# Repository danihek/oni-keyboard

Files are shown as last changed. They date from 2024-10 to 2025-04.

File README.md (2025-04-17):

# Øni keyboard

It's just [sweep36](https://github.com/sadekbaroudi/sweep36/) (specifically swweeep) which is based on [Sweep](https://github.com/davidphilipbarr/Sweep) with custom images on pcb.

List of components:

- 2x [nice!nano v2.0](https://typeractive.xyz/products/nice-nano?variant=42225114546407)
- 4x [10x Kailh Low Profile Choc Pink](https://typeractive.xyz/products/choc-switches?variant=45741919273191)
- 4x [10x Kailh Choc Hotswap Sockets](https://typeractive.xyz/products/hotswap-sockets?variant=45742200324327)
- 1x [2x Power Switch](https://typeractive.xyz/products/power-switch?variant=45597854171367)
- 1x [2x Reset Button](https://typeractive.xyz/products/reset-button?variant=45597784932583)
- 4x [10x Kailh Hotswap Sockets](https://typeractive.xyz/products/hotswap-sockets?variant=45742200324327)
- 2x [Ez Solder Sockets and Headers](https://typeractive.xyz/products/ez-machine-sockets-and-headers?variant=46253860356327)
- 2x [10x MBK Choc Rose Keycaps](https://typeractive.xyz/products/mbk-keycaps?variant=48512019464423)
- 4x [10x MBK Choc Black Keycaps](https://typeractive.xyz/products/mbk-keycaps?variant=45419753079015)
- 2x [Battery 3.7V 110mAh 301230](https://typeractive.xyz/products/lithium-battery-110mah)

# Firmware

I use it with the zmk, here is the conf:
- https://github.com/danihek/oni-keyboard-zmk

# Showcase

## reddit post:
- https://www.reddit.com/r/ErgoMechKeyboards/comments/1ibfym8/oni_keyboard_sweep36/

(images from reddit)






## from JLCPCB Gerber viewer

### Main PCB

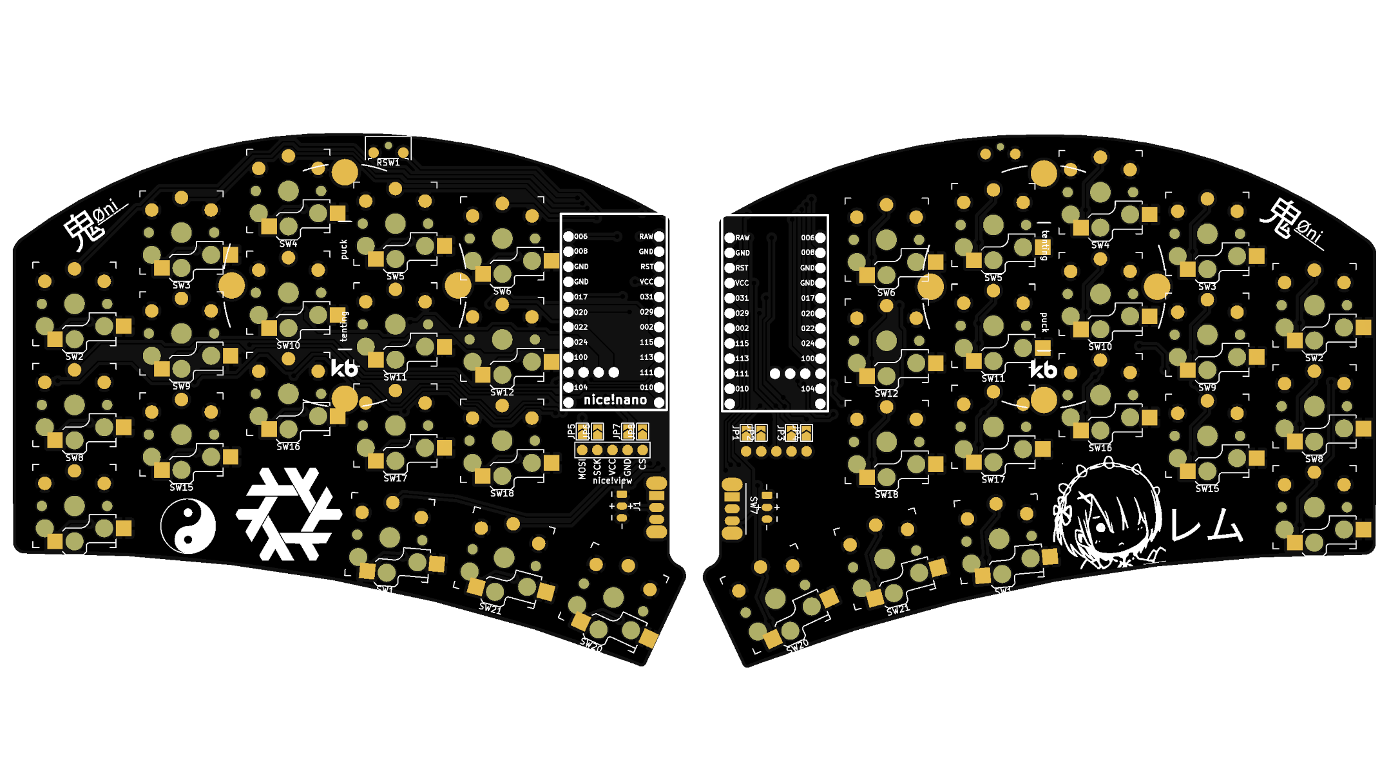
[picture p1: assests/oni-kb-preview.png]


### Base (optional)

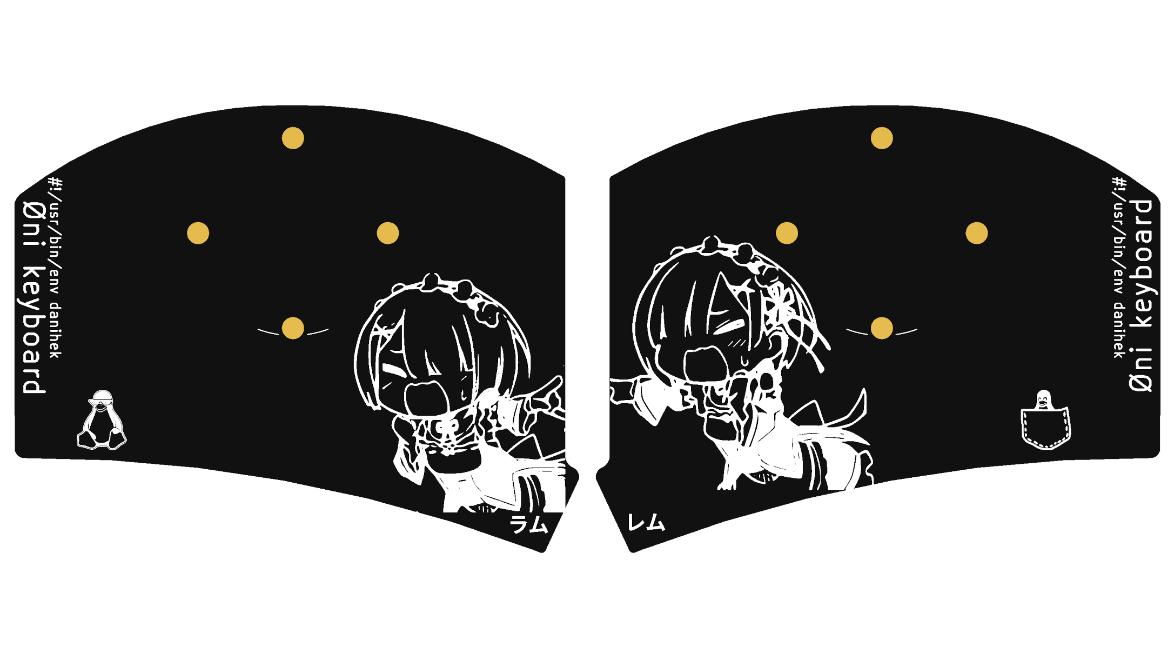
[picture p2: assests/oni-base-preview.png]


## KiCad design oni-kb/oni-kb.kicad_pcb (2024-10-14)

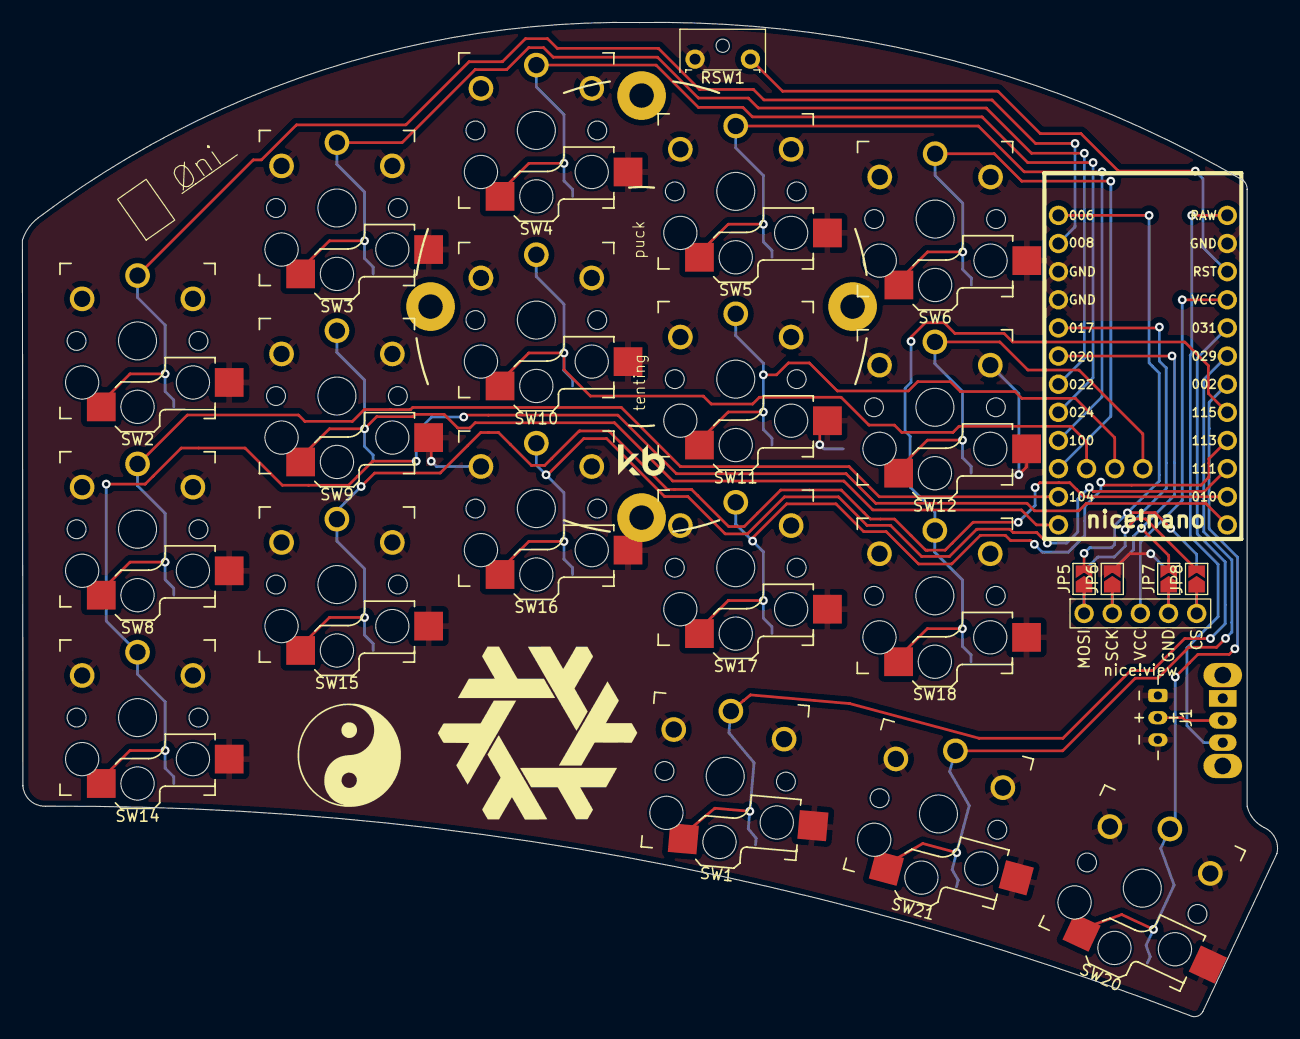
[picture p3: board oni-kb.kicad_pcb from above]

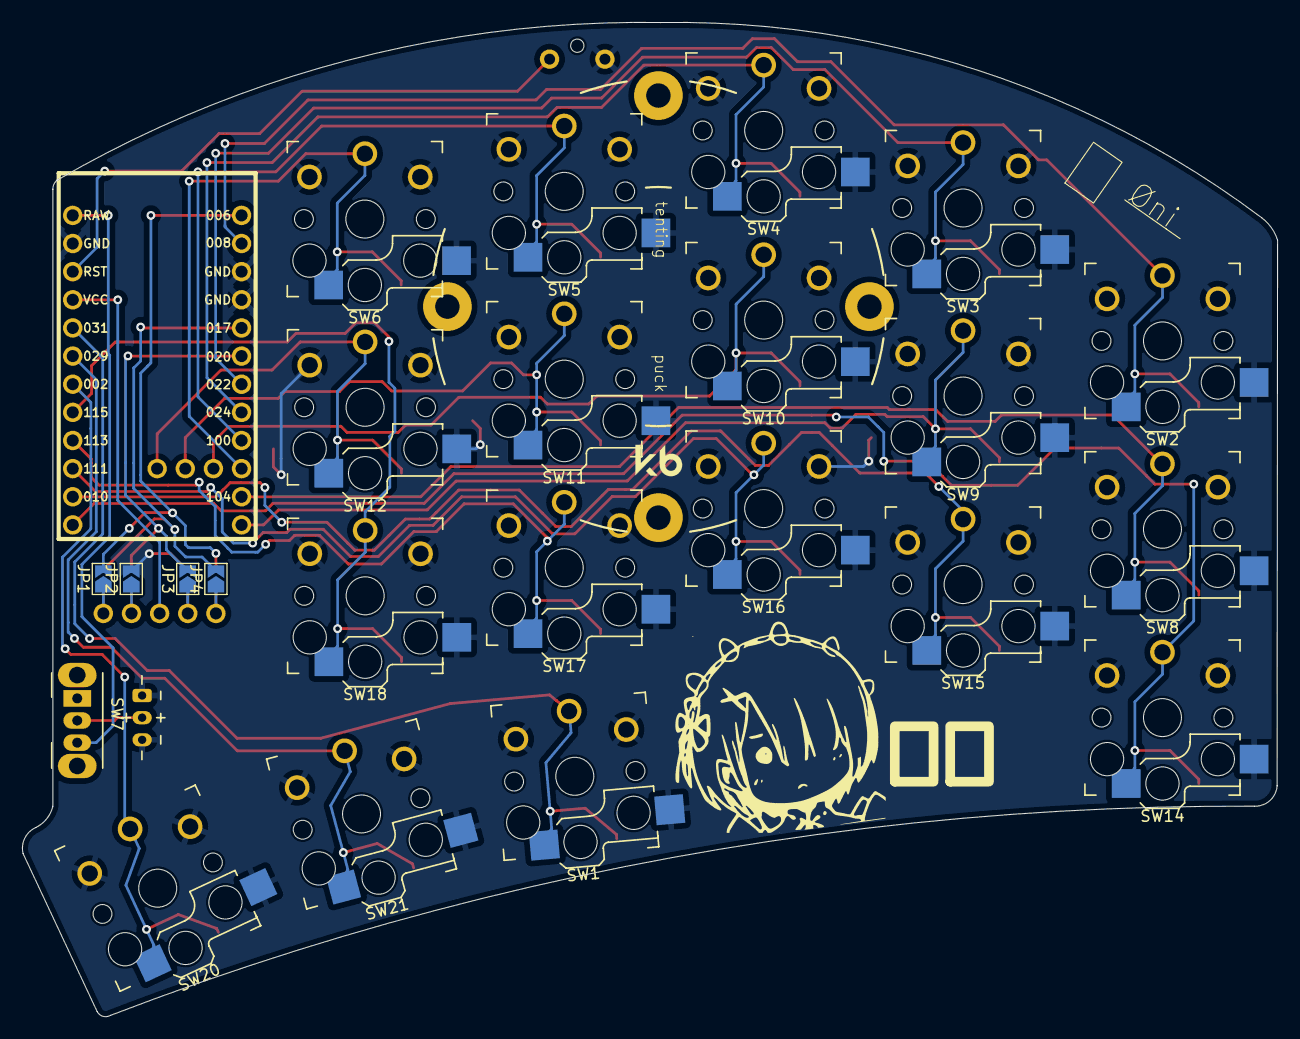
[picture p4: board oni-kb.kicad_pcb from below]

Board: 2 copper layers, 113.3 x 89.7 mm, 34 parts (6 on the bottom side), 30 nets.

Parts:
 : LOGO
 #2,  #3: LOGO
Display1: nice!view; nice_view
J1: JST-BATTERY; JST_PH_S3B-PH-K-keyboard
JP1, JP2, JP3, JP4, JP5, JP6, JP7, JP8: Jumper_2_Open; SolderJumper-2_P1.3mm_Open_TrianglePad1.0x1.5mm
RSW1: SW_Push; SW_Tactile_SPST_Angled_MJTP1117-no-mount
SW1, SW2, SW3, SW4, SW5, SW6, SW8, SW9, SW10, SW11, SW12, SW14, SW15, SW16, SW17, SW18, SW20, SW21: SW_Push; Kailh_socket_PG1350_optional_reversible_millmax
SW7: SW_DPDT; SW_CuK_OS102011MA1QN1_SPDT_Angled
U1: nice_nano

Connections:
unnamed: Display1.1 (MOSI), JP4.1 (A), JP5.1 (A)
unnamed: Display1.2 (SCK), JP3.1 (A), JP6.1 (A)
unnamed: Display1.4 (GND), JP2.1 (A), JP7.1 (A)
unnamed: Display1.5 (CS), JP1.1 (A), JP8.1 (A)
unnamed: J1.2, SW7.2 (B)
Switch1: SW2.1, U1.2 (RX1/P0.08)
Switch2: SW3.1, U1.7 (P0.22)
Switch3: SW4.1, U1.8 (P0.24)
Switch4: SW5.1, U1.9 (P1.00)
Switch5: SW6.1, U1.10 (P0.11)
Switch6: SW8.1, U1.11 (P1.04)
Switch7: SW9.1, U1.12 (P1.06)
Switch8: SW10.1, U1.31 (P1.01)
Switch9: SW11.1, U1.32 (P1.02)
Switch10: SW12.1, U1.33 (P1.07)
Switch11: SW14.1, U1.13 (NFC1/P0.09)
Switch12: SW15.1, U1.14 (NFC2/P0.10)
Switch13: SW16.1, U1.15 (P1.11)
Switch14: SW17.1, U1.16 (P1.13)
Switch15: SW18.1, U1.17 (P1.15)
Switch16: SW20.1, U1.18 (AIN0/P0.02)
Switch17: SW21.1, U1.19 (AIN5/P0.29)
Switch18: SW1.1, U1.20 (AIN7/P0.31)
gnd: J1.1, J1.3, JP2.2 (B), JP6.2 (B), RSW1.1, SW1.2, SW2.2, SW3.2, SW4.2, SW5.2, SW6.2, SW8.2, SW9.2, SW10.2, SW11.2, SW12.2, SW14.2, SW15.2, SW16.2, SW17.2, SW18.2, SW20.2, SW21.2, U1.3 (GND), U1.4 (GND), U1.23 (GND)
mosi: JP4.2 (B), JP8.2 (B), U1.5 (P0.17)
nv_cs: JP1.2 (B), JP5.2 (B), U1.1 (TX0/P0.06)
raw: SW7.3 (C), U1.24 (BATIN/P0.04)
reset: RSW1.2, U1.22 (RST)
sck: JP3.2 (B), JP7.2 (B), U1.6 (P0.20)
vcc: Display1.3 (VCC), U1.21 (VCC)

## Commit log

2024-10-07 Ryōiki Tenkai
    [demo.dxf, keys.dxf, normal.dxf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]
2024-10-10 3 thumb keys
    [board.dxf, demo.dxf, keys.dxf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]
2024-10-14 added text and images
    [oni-base-B_Cu.gbl, oni-base-B_Mask.gbs, oni-base-B_Paste.gbp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]
2024-10-14 readme images
    [oni-base-B_Cu.gbl, oni-base-B_Mask.gbs, oni-base-B_Paste.gbp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]
